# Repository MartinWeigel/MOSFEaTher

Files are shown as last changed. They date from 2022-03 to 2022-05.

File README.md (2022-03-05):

# MOSFEaTher

This PCB provides control of eight MOSFET outputs. These can be controlled through an [Adafruit Feather HUZZAH32](https://www.adafruit.com/product/3405) microcontroller. It is a two-layer PCB and all parts can be handsoldered in case that costs are a concern.

This board was designed using [KiCad 6.0](http://www.kicad.org).

## Design
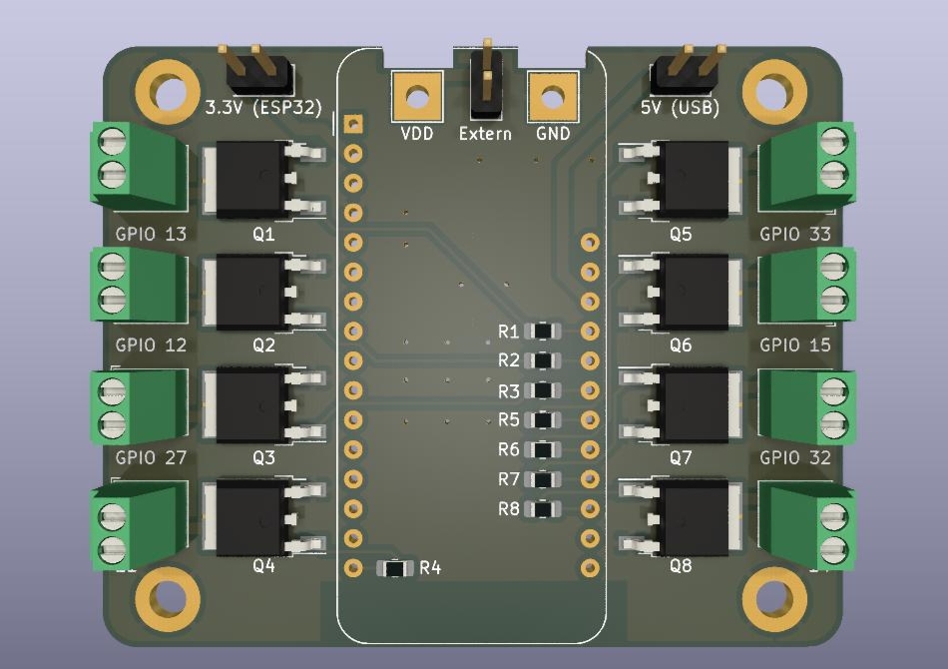
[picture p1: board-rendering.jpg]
Rendering of the board


## Parts
The board requires the following parts. All of them should be easy to handsolder:

Part                   | Quantity | Description
-----------------------|----------|----------------------------
Feather HUZZAH32       | 1        | ESP32 Microcontroller
Phoenix MPT-0,5-2-2.54 | 8        | 2-pin Terminalblock
IRLR024N DPAK MOSFET   | 8        | N-Channel MOSFET (55V 17A)
0805 Resistor 470 Ohm  | 8        | Generic Resistor

## License
<br />This work is licensed under a <a rel="license" href="http://creativecommons.org/licenses/by/4.0/">Creative Commons Attribution 4.0 International License</a>.

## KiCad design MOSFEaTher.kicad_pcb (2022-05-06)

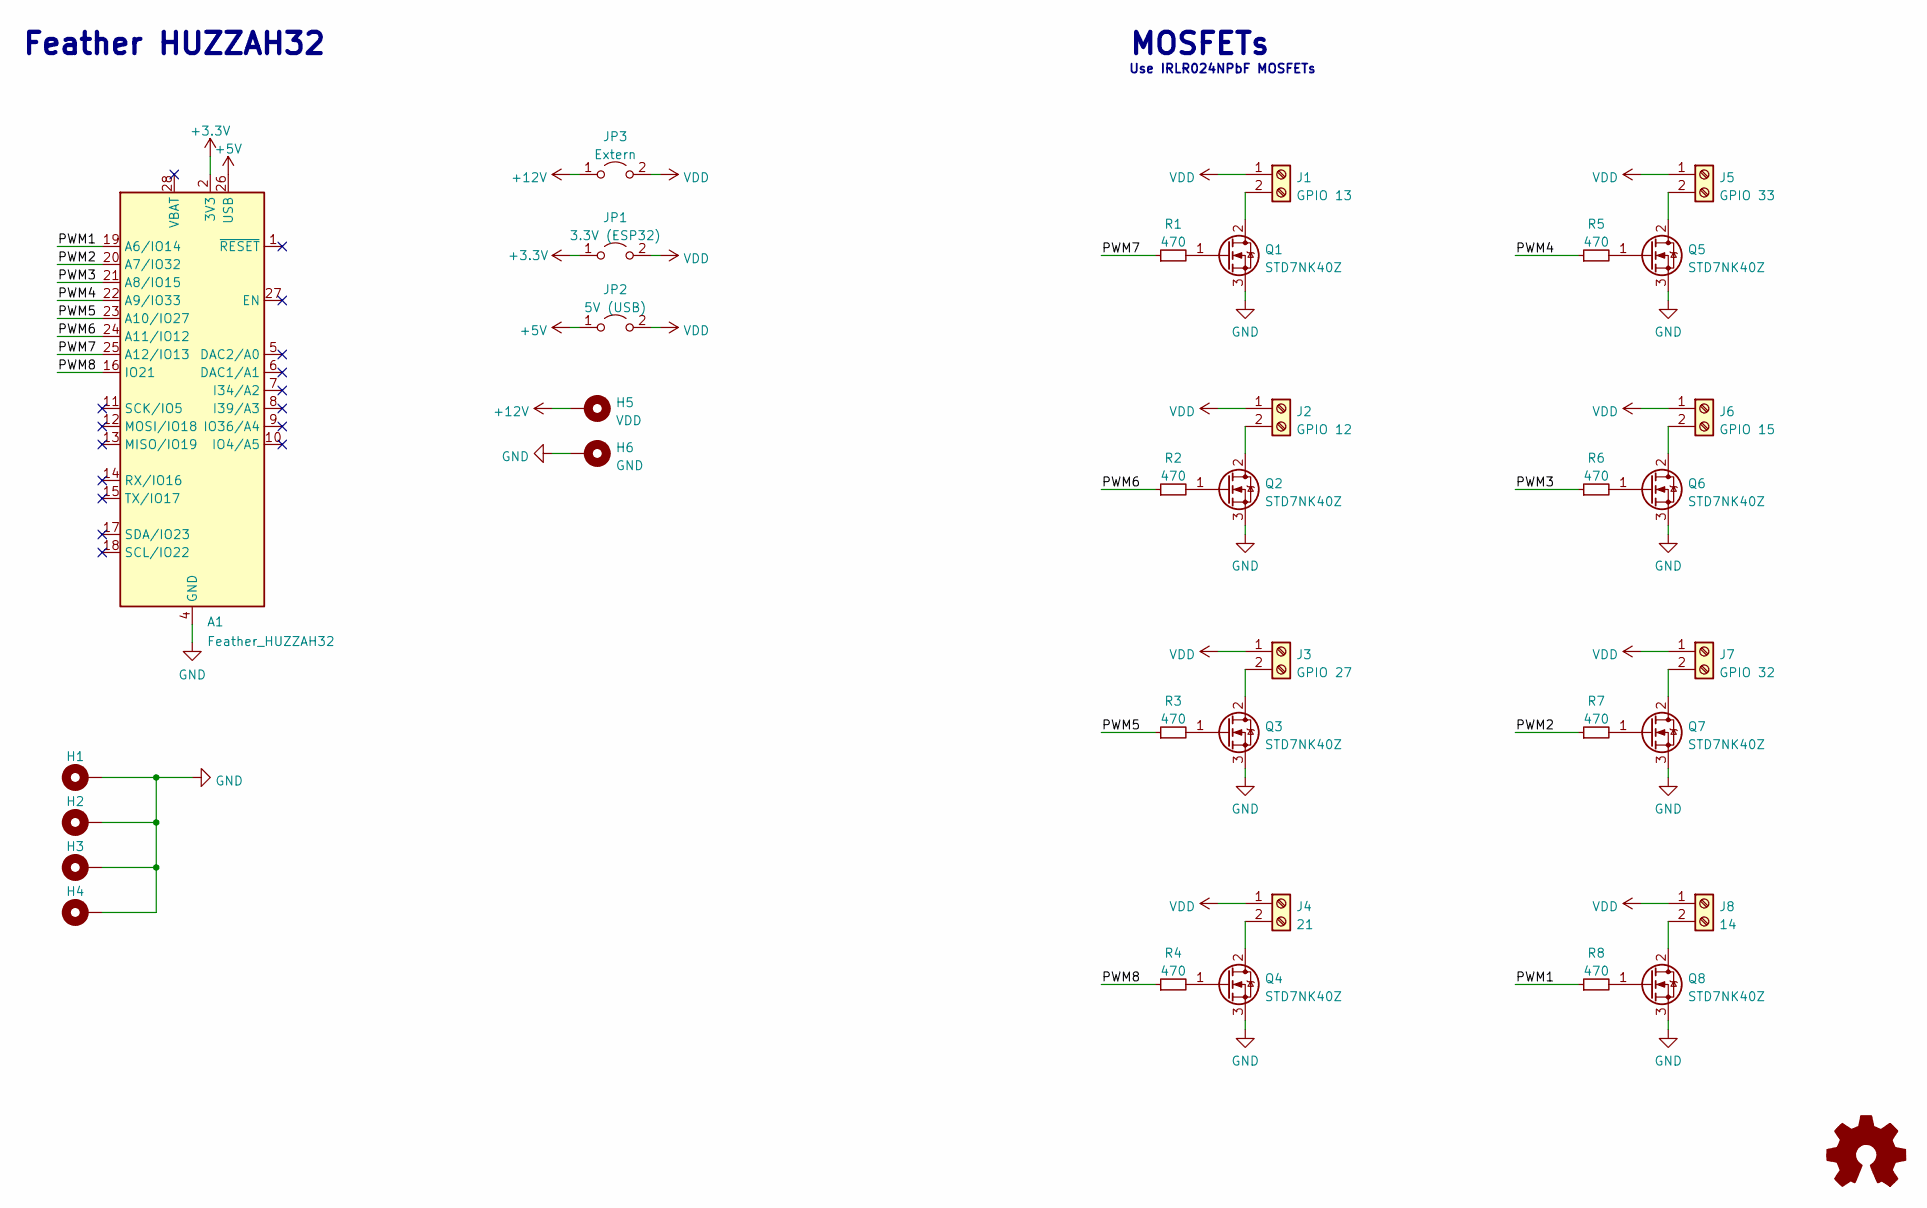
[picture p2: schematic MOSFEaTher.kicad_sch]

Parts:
A1: Feather_HUZZAH32; Adafruit_Feather
H1, H2, H3, H4: MountingHole_Pad; MountingHole_3.2mm_M3_DIN965_Pad
H5: VDD; TestPoint_THTPad_4.0x4.0mm_Drill2.0mm
H6: GND; TestPoint_THTPad_4.0x4.0mm_Drill2.0mm
J1: GPIO 13; TerminalBlock_Phoenix_MPT-0,5-2-2.54_1x02_P2.54mm_Horizontal
J2: GPIO 12; TerminalBlock_Phoenix_MPT-0,5-2-2.54_1x02_P2.54mm_Horizontal
J3: GPIO 27; TerminalBlock_Phoenix_MPT-0,5-2-2.54_1x02_P2.54mm_Horizontal
J4: 21; TerminalBlock_Phoenix_MPT-0,5-2-2.54_1x02_P2.54mm_Horizontal
J5: GPIO 33; TerminalBlock_Phoenix_MPT-0,5-2-2.54_1x02_P2.54mm_Horizontal
J6: GPIO 15; TerminalBlock_Phoenix_MPT-0,5-2-2.54_1x02_P2.54mm_Horizontal
J7: GPIO 32; TerminalBlock_Phoenix_MPT-0,5-2-2.54_1x02_P2.54mm_Horizontal
J8: 14; TerminalBlock_Phoenix_MPT-0,5-2-2.54_1x02_P2.54mm_Horizontal
JP1: 3.3V (ESP32); PinHeader_2x01_P2.54mm_Vertical
JP2: 5V (USB); PinHeader_2x01_P2.54mm_Vertical
JP3: Extern; PinHeader_2x01_P2.54mm_Vertical
Q1, Q2, Q3, Q4, Q5, Q6, Q7, Q8: STD7NK40Z; TO-252-2
R1, R2, R3, R4, R5, R6, R7, R8: 470; R_0805_2012Metric_Pad1.20x1.40mm_HandSolder

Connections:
+3V3: A1.2 (3V3), JP1.1 (A)
+5V: A1.26 (USB), JP2.1 (A)
+12V: H5.1, JP3.1 (A)
/PWM1: A1.19 (A6/IO14), R8.1
/PWM2: A1.20 (A7/IO32), R7.1
/PWM3: A1.21 (A8/IO15), R6.1
/PWM4: A1.22 (A9/IO33), R5.1
/PWM5: A1.23 (A10/IO27), R3.1
/PWM6: A1.24 (A11/IO12), R2.1
/PWM7: A1.25 (A12/IO13), R1.1
/PWM8: A1.16 (IO21), R4.1
GND: A1.4 (GND), H1.1, H2.1, H3.1, H4.1, H6.1, Q1.3 (S), Q2.3 (S), Q3.3 (S), Q4.3 (S), Q5.3 (S), Q6.3 (S), Q7.3 (S), Q8.3 (S)
unnamed: J1.2, Q1.2 (D)
unnamed: J2.2, Q2.2 (D)
unnamed: J3.2, Q3.2 (D)
unnamed: J4.2, Q4.2 (D)
unnamed: J5.2, Q5.2 (D)
unnamed: J6.2, Q6.2 (D)
unnamed: J7.2, Q7.2 (D)
unnamed: J8.2, Q8.2 (D)
unnamed: Q1.1 (G), R1.2
unnamed: Q2.1 (G), R2.2
unnamed: Q3.1 (G), R3.2
unnamed: Q4.1 (G), R4.2
unnamed: Q5.1 (G), R5.2
unnamed: Q6.1 (G), R6.2
unnamed: Q7.1 (G), R7.2
unnamed: Q8.1 (G), R8.2
VDD: J1.1, J2.1, J3.1, J4.1, J5.1, J6.1, J7.1, J8.1, JP1.2 (B), JP2.2 (B), JP3.2 (B)

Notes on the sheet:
Feather HUZZAH32
MOSFETs
Use IRLR024NPbF MOSFETs

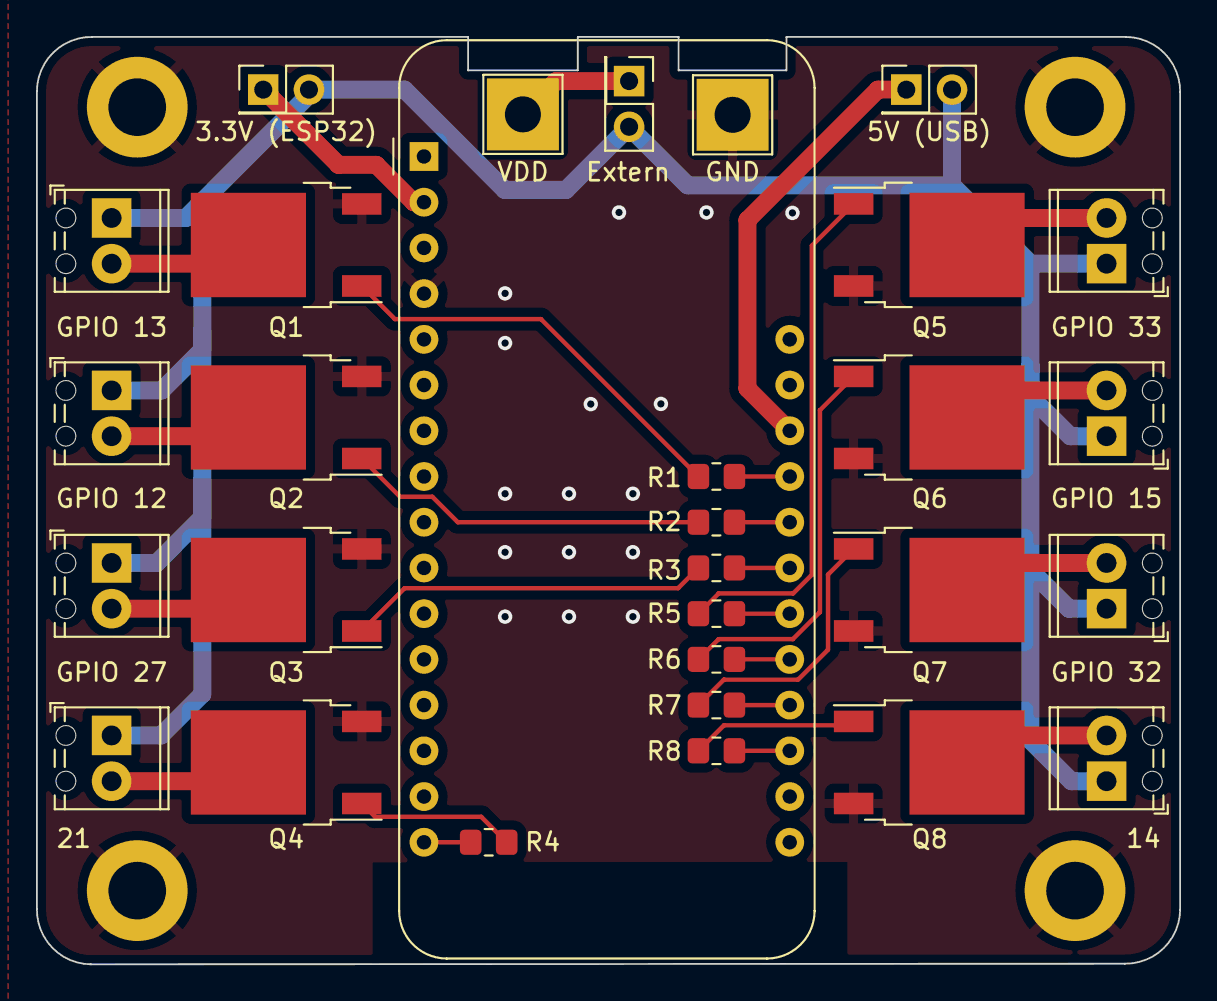
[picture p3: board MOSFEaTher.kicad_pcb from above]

Board: 2 copper layers, 63.5 x 51.5 mm, 34 parts (0 on the bottom side), 29 nets.

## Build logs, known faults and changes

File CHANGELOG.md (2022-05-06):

# Changelog

## v03
- Additional jumper for external power
- Ground fills on both PCB sides
- More distance between signal wires

## v02
- M3 instead of M2 mounting holes
- Add Open Hardware Logo
- Acknowledge Technische Hochschule Mittelhessen

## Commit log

2022-03-05 feat: first version of MOSFEaTher
    [MOSFEaTher.kicad_pcb, MOSFEaTher.kicad_sch]
2022-03-21 feat: M3 mounting holes, OSHW logo and THM affiliation
    [MOSFEaTher.kicad_pcb, MOSFEaTher.kicad_sch]
2022-05-06 feat: better power and signal routing
    [MOSFEaTher.kicad_pcb, MOSFEaTher.kicad_sch]

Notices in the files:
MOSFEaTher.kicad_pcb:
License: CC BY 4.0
